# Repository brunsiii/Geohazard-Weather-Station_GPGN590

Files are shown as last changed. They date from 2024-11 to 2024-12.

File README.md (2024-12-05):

# Geohazard-Weather-Station_GPGN590
Multiparameter Geohazard monitoring station with Arduino
## Abstract
Geologic hazards, such as landslides or avalanches, pose significant risks to communities, infrastructure, and ecosystems. Understanding the factors that influence these events is crucial for effective risk management and mitigation strategies. This project aims to develop a cost-effective weather station situated on a slow-moving landslide, utilizing low-cost instrumentation such as Arduino microcontrollers. The system will monitor key environmental parameters, including temperature, humidity, soil moisture, and movement patterns, which are essential for assessing landslide stability. By leveraging open-source technologies, we aim to provide an accessible solution that enables real-time data collection and analysis, fostering greater awareness of landslide behavior. The gathered data will enhance predictive models, support research efforts, and ultimately contribute to the development of early warning systems, thereby improving safety and preparedness in vulnerable regions. Through this project, we aim to demonstrate that innovative, low-cost solutions can play a vital role in addressing natural hazards and enhancing community resilience.

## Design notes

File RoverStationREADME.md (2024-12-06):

# Rover Station Design and Construction
The rover station is designed to measure GPS, Magnetometer, temperature, humidity, and pressure data and then compile and transmit all data to base station via XBee.
## Hardware Requirements
- Arduino Mega 2560
-     https://store.arduino.cc/products/arduino-mega-2560-rev3
- XBee Pro S3B
-     https://www.digi.com/products/embedded-systems/digi-xbee/rf-modules/sub-1-ghz-rf-modules/xbee-pro-xsc
- XBee Shield V2 For Arduino
-     https://www.tinyosshop.com/Xbee%20Shield
- BN-880 GPS
-     https://www.amazon.com/Geekstory-Navigation-Raspberry-Aircraft-Controller/dp/B078Y6323W?th=1
- BME 688 Temperature/Pressure/Humidity Sensor
-     https://www.adafruit.com/product/5046

## Construction Instructions
1. Stack XBee Shield V2 for Arduino on top of the Arduino Mega 2560 - this is the Transmitting Arduino.
2. Place intialized Rover XBee Pro S3B into Rover XBee Shield. For instructions on XBee initialization see XBeeREADME.md.
3. Connect GPS Magnetometer and BME 688 to Transmitting Arduino. The GPS Magnetometer connects directly to the RX1 (pin 19) and TX1 (pin 18) pins on the Arduino, and to the 5v and GND pins on the XBee Shield. The BME 688 connects to the 3.5V and GND as well as the SCA adn SCL pins on the Xbee Shield. The RX, TX, SCA, and SCL pins are for transmitting data from the sensor to the base station.
## Uploading Code
1. Plug Arduino into a computer via USB.
2. Compile and upload gpsmagtemp.ino to Transmitting Arduino. Ensure that the MCU-PC switch is set to PC on XBee Shield.
## Communicating with Base
1. Once the Rover has been properly initialized, flip PC to MCU on XBee Shield. See BaseStationREADME.md for instructions on how to construct and intialize the Base Station.
2. To run independently, unplug Arduino from laptop and power with a 9V battery.

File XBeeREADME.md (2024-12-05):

# XBee Communication Initialization
## Software Requirements
- XCTU
- Arduino IDE
## Hardware Requirements
- XBee Pro S3B (2)
-     https://www.digi.com/products/embedded-systems/digi-xbee/rf-modules/sub-1-ghz-rf-modules/xbee-pro-xsc
- XBee Grove Dev Board (2)
-     https://www.digi.com/resources/documentation/digidocs/90001942-13/containers/cont_xbee_grove_development_board.htm
- MicroUSB to USB cable for communication with PC
- Arduino Mega 2560
-     https://store.arduino.cc/products/arduino-mega-2560-rev3
- XBee Shield V2 For Arduino (2)
-     https://www.tinyosshop.com/Xbee%20Shield
## Setting Base and Rover Pairs in XCTU
1. Plug both XBee Pro S3Bs into XBee Grove Dev Boards and connect Dev Boards to computer via USB.
### Add Radio Devices
1. Open XCTU software
2. If connecting for first time, press the "Add radio module" button
3. Choose Serial/USB port for first XBee
4. Set the following parameters: Baud Rate = 9600; Data Bits = 8; Parity = None; Stop Bits = 1; Flow Control = None
5. Click "Finish"
6. Repeat steps 1-5 for a second XBee
### Intialize Base Station
1. Click on the first XBee and then click the gear icon to access its settings.
2. Under section titled "MAC/PHY" configure the following settings: Network ID = 1001; Broad ast Multi-Transmits = 3; TX Power Level = Highest [4]
3. Under section titled "Network" configure the following settings: Routing/Messaging Mode = Indirect Msg Coordinator [1]
4. Under section titled "Addressing" configure the following settings: Destination Address High = 0; Destination Address Low = FFFF; Node Identifier = Base
### Initialize Rover Station
1. Click on the second XBee and then click the gear icon to access its settings.
2. Under section titled "MAC/PHY" configure the following settings: Network ID = 1001; Broad ast Multi-Transmits = 3; TX Power Level = Highest [4]
3. Under section titled "Network" configure the following settings: Routing/Messaging Mode = Indirect Msg Coordinator [1]
4. Under section titled "Addressing" configure the following settings: Destination Address High = 0; Destination Address Low = FFFF; Node Identifier = Rover
## Communicating Data
1. Plug in XBee Shield V2 For Arduino to Base Receiving Arduino Mega 2560. Repeat for Rover.
2. Unplug Rover XBee S3B from Dev Board and plug into Rover XBee Shield V2 for Arduino. Repeat for Base.
3. Ensure that the PC-MCU switch on the XBee Shield V2 for Arduino board is set to PC for both Shields.
4. Upload gpsmagxbee.ino code to Rover Arduino to send GPS/Magnetometer data to Rover XBee to be communicated to Base.
5. Upload BaseStation1.ino code to Receviing Arduino to receive GPS/Magnetometer data from Rover XBee.
6. If saving code to SD card, add SD card breakout board to third Saving Arduino. Ensure SD card is inserted before powering on Saving Arduino.
7. Connect pins D18 and D19 on Receiving to pins D19 and D18 on Saving respectively.
8. Once code is uploaded and base station arduino wire connections made between Serial1 pins, switch PC to MCU on both XBee Shields. This allows the Magnetometer/GPS data to be transmitted from Rover to Base.
9. Unplug serial USBs from all three Arduinos. Plug 9V batteries into al three Arduinos.
10. You can check that data is being received and saved by powering off the saving base station Arduino, unplugging the SD card, and loading onto a laptop. Data should be in a comma separated .TXT file.

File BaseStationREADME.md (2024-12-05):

# Base Station Design and Construction
The base station is designed to receive transmitted data and store them on an SD card.
## Hardware Requirements
- Arduino Mega 2560 (2)
-     https://store.arduino.cc/products/arduino-mega-2560-rev3
- XBee Pro S3B
-     https://www.digi.com/products/embedded-systems/digi-xbee/rf-modules/sub-1-ghz-rf-modules/xbee-pro-xsc
- XBee Shield V2 For Arduino
-     https://www.tinyosshop.com/Xbee%20Shield
- Male-to-male jumper cables (2)
- Ethernet/SD Card Shield
-     https://www.amazon.com/Ethernet-Shield-Network-Expansion-Arduino/dp/B00AXVX5D0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
- MicroSD Card
## Construction Instructions
1. Stack XBee Shield V2 for Arduino on top of the first Arduino Mega 2560 - this is the Receiving Arduino.
2. Place intialized Base XBee Pro S3B into Base XBee Shield. For instructions on XBee initialization see XBeeREADME.md.
3. Stack Ethernet/SD Card Shield on top of Arduino Mega 2560 - this is the Saving Arduino.
4. Connect pins D18 and D19 of Receiving Arduino to pins D19 and D18 of Saving Arduino. Connecting these respective RX and TX pins establishes the Serial1 connection referenced in the BaseStation1.ino and SavingBaseStation.ino codes.
5. Insert MicroSD card into Ethernet/SD Card Shield.
## Uploading Code
1. Plug both Arduinos into a computer via USB.
2. Compile and upload BaseStation1.ino to Receviing Arduino. Ensure that the MCU-PC switch is set to PC on XBee Shield.
3. Compile and upload SavingBaseStation.ino to Saving Arduino.
## Communicating with Rover and Saving Data
1. Once the Rover has been properly initialized, flip PC to MCU on XBee Shield. See RoverStationREADME.md for instructions on how to construct and intialize the Rover Station.
2. To run independently, unplug Arduinos from laptop and power with 9V batteries.
3. Data should flow to Receiving Arduino and be saved to the SD card on the Saving Arduino.
4. Always power down arduinos before inserting or removing the SD card.

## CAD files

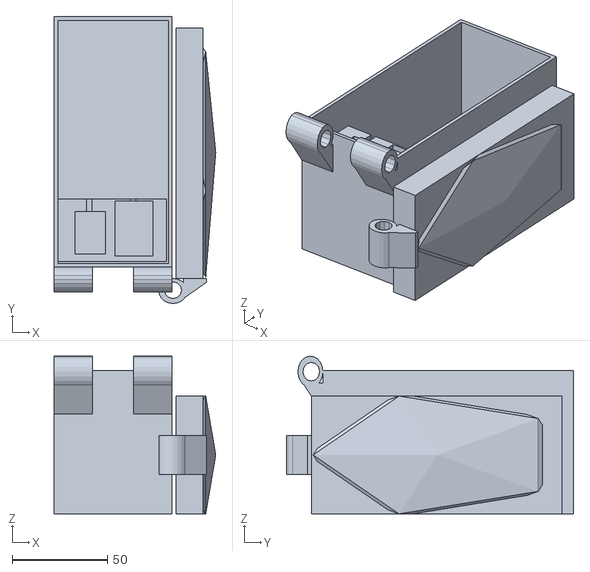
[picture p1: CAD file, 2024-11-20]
GPGN590-Box-and-Lid.stl
85.0 x 151.0 x 83.0

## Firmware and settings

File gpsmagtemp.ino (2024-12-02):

// This code was originally adapted from code used in Module 7 of this class originally sourced from Noah Perkovich and Ethan Deal. 
// ChatGPT was used to generate portions of this code (OpenAI, 2024, October 15 Version).
// Specifically, ChatGPT was used to initialize communication via serial, and to communicate data from serial monitor to XBee and vice versa, as well as intializing data out through pins zero and one on the Arduino (OpenAI, 2024, October 15 Version).
#include <Wire.h>
#include <TinyGPS++.h>
#include <SPI.h>
#include <Adafruit_Sensor.h>
#include "Adafruit_BME680.h"

// GPS and sensor instances
TinyGPSPlus gps;
Adafruit_BME680 bme; // I2C

const int magnetometerAddress = 0x1E;  // Magnetometer I2C address
unsigned long lastPrintTime = 0;
bool headerSent = false;  // Track if the header has been sent

void setup() {
  Serial.begin(9600);  // Initialize serial communication with PC and XBee
  Serial1.begin(9600); // Start GPS communication on Serial1 (pins 18/19)
  Wire.begin();        // Start I2C communication for the magnetometer

  Serial.println("Initializing BN-880 GPS + HMC5883L Magnetometer + BME680...");

  // Initialize Magnetometer (HMC5883L specific setup)
  Wire.beginTransmission(magnetometerAddress);
  Wire.write(0x00);    // Configuration Register A
  Wire.write(0x70);    // 8-average, 15 Hz default, normal measurement
  Wire.endTransmission();

  Wire.beginTransmission(magnetometerAddress);
  Wire.write(0x01);    // Configuration Register B
  Wire.write(0xA0);    // Gain = 5
  Wire.endTransmission();

  Wire.beginTransmission(magnetometerAddress);
  Wire.write(0x02);    // Mode Register
  Wire.write(0x00);    // Continuous measurement mode
  byte error = Wire.endTransmission();

  if (error == 0) {
    Serial.println("HMC5883L Magnetometer initialized successfully!");
  } else {
    Serial.print("ERROR: Magnetometer initialization failed. I2C Error Code: ");
    Serial.println(error);
  }

  // Initialize BME680 sensor
  if (!bme.begin()) {
    Serial.println("Could not find a valid BME680 sensor, check wiring!");
    while (1);
  }
  
  // Set up oversampling and filter initialization
  bme.setTemperatureOversampling(BME680_OS_8X);
  bme.setHumidityOversampling(BME680_OS_2X);
  bme.setPressureOversampling(BME680_OS_4X);
  bme.setIIRFilterSize(BME680_FILTER_SIZE_3);
  bme.setGasHeater(320, 150); // 320°C for 150 ms

  // 1-minute delay before starting transmission
  Serial.println("Waiting for 1 minute before transmission...");
  delay(1000);  // Wait for 1 seconds
}

void readMagnetometer(float &magX, float &magY, float &magZ) {
  Wire.beginTransmission(magnetometerAddress);
  Wire.write(0x03);  // Starting register for data output
  Wire.endTransmission();

  Wire.requestFrom(magnetometerAddress, 6);  // Request 6 bytes (X, Z, Y)

  if (Wire.available() == 6) {
    int16_t x = Wire.read() << 8 | Wire.read();  // X-axis data
    int16_t z = Wire.read() << 8 | Wire.read();  // Z-axis data
    int16_t y = Wire.read() << 8 | Wire.read();  // Y-axis data

    // Convert raw data to microteslas (µT) based on gain setting (0.92 µT/LSB)
    magX = (float)x * 0.92;
    magY = (float)y * 0.92;
    magZ = (float)z * 0.92;
  } else {
    Serial.println("WARNING: Magnetometer data not available.");
  }
}

void loop() {
  // Parse GPS data from Serial1 (connected to GPS module)
  while (Serial1.available() > 0) {
    gps.encode(Serial1.read());
  }

  // Check if 1/2 second has passed
  if (millis() - lastPrintTime >= 500) {
    lastPrintTime = millis();

    // Send header once
    if (!headerSent) {
      Serial.println("Latitude,Longitude,Time,Magnetometer_X(µT),Magnetometer_Y(µT),Magnetometer_Z(µT),Temperature,Humidity,Pressure,Gas Resistance");
      headerSent = true;
    }

    // Read Magnetometer data
    float magX = 0, magY = 0, magZ = 0;
    readMagnetometer(magX, magY, magZ);

    // Read BME680 data
    if (!bme.performReading()) {
      Serial.println("Failed to perform reading from BME680 :(");
      return;
    }

    // Create a string to store the CSV-formatted data
    String dataString = "";

    // Add GPS data if available
    if (gps.location.isValid()) {
      dataString += String(gps.location.lat(), 6) + ",";  // Latitude
      dataString += String(gps.location.lng(), 6) + ",";  // Longitude
    } else {
      dataString += ",";  // Leave empty for Latitude
      dataString += ",";  // Leave empty for Longitude
    }

    // Add time if available
    if (gps.time.isValid()) {
      dataString += String(gps.time.hour()) + ":" + String(gps.time.minute()) + ":" + String(gps.time.second()) + ",";  // Time
    } else {
      dataString += ",";  // Leave empty for Time
    }

    // Add Magnetometer data
    dataString += String(magX) + ",";  // Magnetometer X
    dataString += String(magY) + ",";  // Magnetometer Y
    dataString += String(magZ) + ",";  // Magnetometer Z

    // Add BME680 data
    dataString += String(bme.temperature, 1) + ",";     // Temperature
    dataString += String(bme.humidity, 1) + ",";        // Humidity
    dataString += String(bme.pressure / 1000.0000, 6) + ","; // Pressure in kPa
    dataString += String(bme.gas_resistance);            // Gas Resistance

    // Send the data to the XBee and Serial Monitor
    Serial.println(dataString);
  }
  
  delay(500);  // Delay between loops (0.5 second)
}

// References
// OpenAI. (2024). ChatGPT (October 15 version) [Large language model].

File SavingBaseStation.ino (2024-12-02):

// This code was adpated from Arduino Workshop, "Project 22 - Writing Data to the Memory Card" such that the communicated data is saved to an SD card (Boxall, 2021, pp. 140–141).
// ChatGPT was consulted to troubleshoot the saving mechanisms of the following code (OpenAI, 2024, November 14 Version).
// Project 22 - Writing Data to the Memory Card (Boxall, 2021, pp. 140–141)
#include <SD.h>
int b = 0;
void setup()
{
  Serial.begin(9600);
  Serial1.begin(9600);
  Serial.println("Initializing SD card...");
  pinMode(4, OUTPUT);
  // check that the memory card exists and is usable
  if (!SD.begin(4))
  {
    Serial.println("Card failed, or not present");
    // stop sketch
    return;
  }
  Serial.println("memory card is ready");
}
void loop()
{
    // Check if there is data available from the XBee (connected to Serial)
  if (Serial1.available()) {
    char receivedByte = Serial1.read();  // Read a byte from the XBee
    
    // Print the received byte to the Serial Monitor (USB)
    Serial.print("Received Byte: ");
    Serial.println(receivedByte);
  
  // create the file for writing
  File dataFile = SD.open("SAVE.TXT", FILE_WRITE);
  // if the file is ready, write to it:
  if (dataFile)
  {
    dataFile.print(receivedByte);
    dataFile.close(); // close the file once the system has finished with it
                      // (mandatory)
  }
  // if the file isn't ready, show an error:
  else
  {
    Serial.println("error opening DATA.TXT");
  }
  }
  delay(5);
}

// References
// Boxall, J. (2021). Arduino workshop: A hands-on introduction with 65 projects (2nd edition). No Starch Press.
// OpenAI. (2024). ChatGPT (November 14 version) [Large language model].
